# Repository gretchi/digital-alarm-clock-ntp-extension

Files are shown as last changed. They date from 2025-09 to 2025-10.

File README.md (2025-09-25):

# digital-alarm-clock-ntp-extension

## ボタン配置

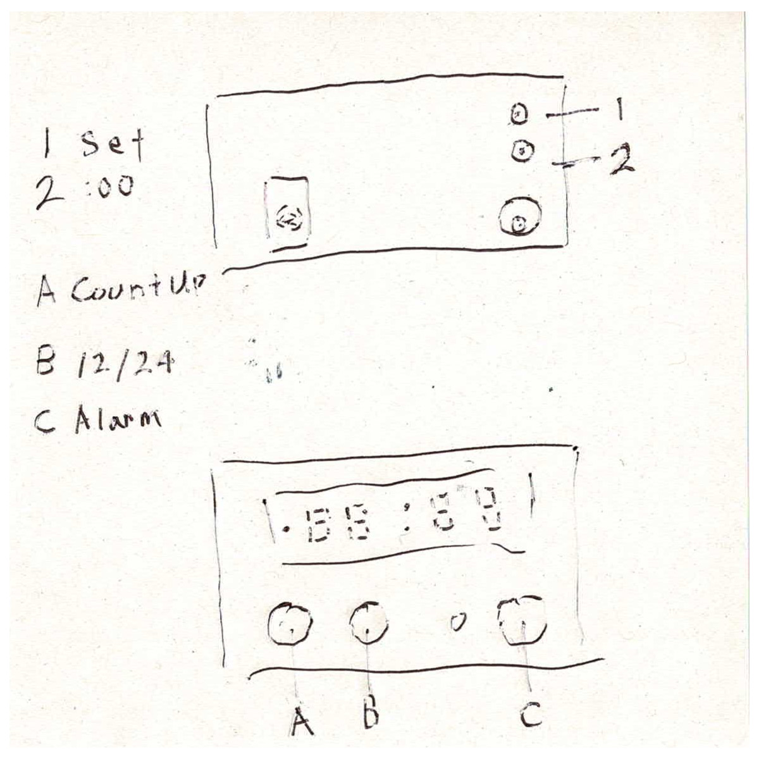
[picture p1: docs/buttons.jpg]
buttons


## フロー

### ブート

1. ネットワーク確立
2. NTP日時取得

### 電源投入直後

1. `Btn_1` High -> Low (時計を開始)

### 日時合わせ

1. ボタン操作回数を計算し、操作開始をスケジュール
    1. ssが正時となるタイミングにmm + 1回目のエミュレートが行われるようエミュレート開始タイミングをスケジュール
2. `Btn_1` High -> Low
3. `Btn_A` hh++
4. `Btn_B` mm++

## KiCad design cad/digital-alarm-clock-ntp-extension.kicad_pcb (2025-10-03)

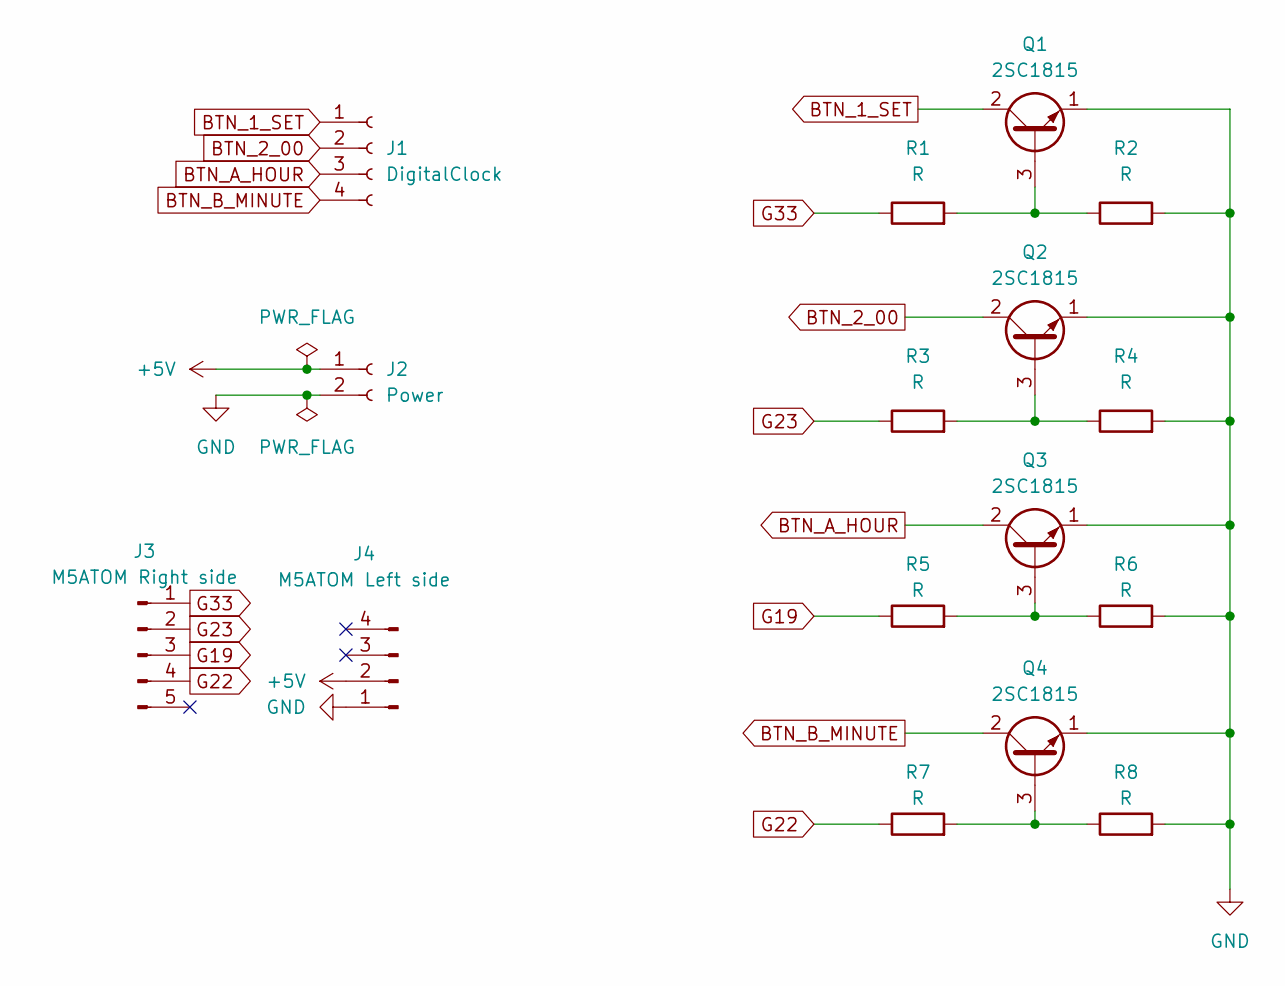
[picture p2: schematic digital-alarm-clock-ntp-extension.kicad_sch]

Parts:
J1: DigitalClock; JST_XH_B4B-XH-A_1x04_P2.50mm_Vertical
J2: Power; JST_XH_B2B-XH-A_1x02_P2.50mm_Vertical
J3: M5ATOM Right side; PinHeader_1x05_P2.54mm_Vertical
J4: M5ATOM Left side; PinHeader_1x04_P2.54mm_Vertical
Q1, Q2, Q3, Q4: 2SC1815; TO-92_Inline_Wide
R1, R3, R5, R7: R; R_Axial_DIN0207_L6.3mm_D2.5mm_P10.16mm_Horizontal
R2, R4, R6, R8: R; R_Axial_DIN0204_L3.6mm_D1.6mm_P5.08mm_Vertical

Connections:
+5V: J2.1, J4.2
BTN_1_SET: J1.1, Q1.2 (C)
BTN_2_00: J1.2, Q2.2 (C)
BTN_A_HOUR: J1.3, Q3.2 (C)
BTN_B_MINUTE: J1.4, Q4.2 (C)
G19: J3.3, R5.1
G22: J3.4, R7.1
G23: J3.2, R3.1
G33: J3.1, R1.1
GND: J2.2, J4.1, Q1.1 (E), Q2.1 (E), Q3.1 (E), Q4.1 (E), R2.2, R4.2, R6.2, R8.2
unnamed: Q1.3 (B), R1.2, R2.1
unnamed: Q2.3 (B), R3.2, R4.1
unnamed: Q3.3 (B), R5.2, R6.1
unnamed: Q4.3 (B), R7.2, R8.1

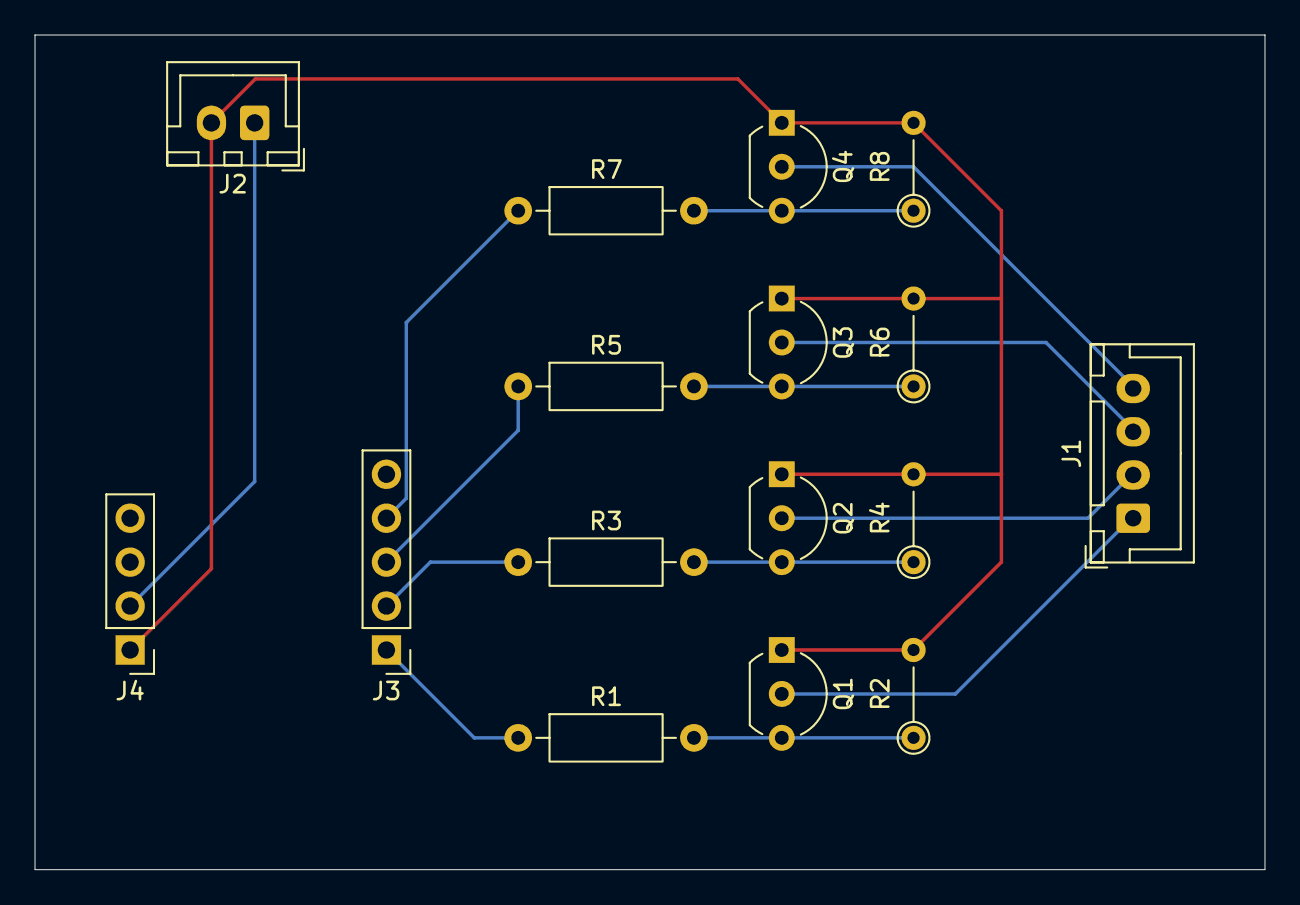
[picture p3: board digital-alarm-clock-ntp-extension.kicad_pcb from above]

Board: 2 copper layers, 71.1 x 48.3 mm, 16 parts (0 on the bottom side), 14 nets.

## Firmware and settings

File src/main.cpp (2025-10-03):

#include <Arduino.h>
#include <M5Atom.h>
#include <WiFiManager.h>
#include <WiFi.h>
#include "app_wifi.h"

const int BTN_1_SET = 33;
const int BTN_2_00 = 23;
const int BTN_A_HOUR = 19;
const int BTN_B_MINUTE = 22;
const int PRESS_MS = 100;

extern WiFiManager wm;
extern String configure_ssid;
extern String configure_password;

void press_ms(int gpio, int ms);

void setup()
{
    M5.begin(true, false, true);
    Serial.begin(115200);
    M5.dis.drawpix(0, 0xFF0000);

    pinMode(BTN_1_SET, INPUT);
    pinMode(BTN_2_00, INPUT);
    pinMode(BTN_A_HOUR, INPUT);
    pinMode(BTN_B_MINUTE, INPUT);

    initAppWiFi();
    Serial.printf("Configure Wi-Fi SSID: %s, Password: %s\n", configure_ssid.c_str(), configure_password.c_str());
    if (WiFiConnect() == 0)
    {
        Serial.println("Wi-Fi not connecting");
    }
    M5.dis.drawpix(0, 0x008000);

    press_ms(BTN_1_SET, PRESS_MS);
    delay(5000);

    press_ms(BTN_1_SET, PRESS_MS);
    for (int i = 0; i < 3; i++)
    {
        press_ms(BTN_A_HOUR, PRESS_MS);
        delay(300);
    }
    for (int i = 0; i < 15; i++)
    {
        press_ms(BTN_B_MINUTE, PRESS_MS);
        delay(300);
    }
}

void press_ms(int gpio, int ms)
{
    pinMode(gpio, OUTPUT);
    M5.dis.drawpix(0, 0x0080FF);
    digitalWrite(gpio, HIGH);
    delay(ms);
    pinMode(gpio, INPUT);
    M5.dis.drawpix(0, 0x008000);
    delay(ms);
}

void loop()
{
    M5.update();
    delay(100);
}

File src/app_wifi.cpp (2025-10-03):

#include "app_wifi.h"

#include <Arduino.h>
#include "M5Atom.h"

WiFiManager wm;
extern bool is_loop;

const String password_spec_chars = "2345679abcdefghjkmnopqrstuvwxyzACDEFGHJKLMNOPQRSTUVWXYZ"; // 55文字

String configure_ssid = "";
String configure_password = "";

void generateConfigureSSID()
{
    String mac_addr = String(WiFi.macAddress());
    mac_addr.replace(":", "");

    configure_ssid = "DigitalClock"
                     "_" +
                     mac_addr;
}

void initAppWiFi()
{
    generateConfigureSSID();
    generateConfigurePassword();
}

void generateConfigurePassword()
{
    String mac_addr = String(WiFi.macAddress());
    mac_addr.replace(":", "");
    char bytes_mac_addr[13] = {};
    mac_addr.toCharArray(bytes_mac_addr, 13);

    uint64_t seed = 0;
    for (int i = 0; i < 8; i++)
    {
        char c = bytes_mac_addr[12 - i];
        seed = seed << 8 | (uint64_t)c & 0xFF;
    }

    seed ^= 0x543D3449AC073FA0LL; // デタラメな数列をXOR

    // 乱数生成器初期化
    randomSeed(seed);

    configure_password = "";

    for (int i = 0; i < 10; i++)
    {
        int s = random(55);
        configure_password = configure_password + password_spec_chars.substring(s, s + 1);
    }
}

void getSSID(char *ssidBuffer, size_t bufferSize)
{
    String ssid = WiFi.SSID();

    strncpy(ssidBuffer, ssid.c_str(), bufferSize - 1);
    ssidBuffer[bufferSize - 1] = '\0';
}

int WiFiConnect()
{
    if (WiFi.isConnected())
    {
        Serial.println("already connected");
        return 0;
    }

    // 設定済みWi-Fiへ接続
    wm.setEnableConfigPortal(false);

    for (int i = 0; i < 3; i++)
    {
        if (wm.autoConnect())
        {
            Serial.println("successful new connection");
            return 0;
        }

        delay(5000);
        Serial.println("retry to connect");
    }

    // 新規接続
    wm.setEnableConfigPortal(true);

    if (wm.autoConnect(configure_ssid.c_str(), configure_password.c_str()))
    {
        if (WiFi.psk().compareTo("") == 0)
        {
            // オープンネットワークへの接続は禁止
            Serial.println("connecting to an open network is prohibited");
            wm.resetSettings();
            ESP.restart();
        }
        Serial.println("successful new connection");
        return 0;
    }

    Serial.println("failed to connect");

    return -1;
}

// void wifi_state()
// {
//     static bool wifi_status_lump_state = 0;

//     if (WiFi.status() == WL_CONNECTED)
//     {
//         // Wi-Fi接続中
//         M5.dis.drawpix(PIX_POS_WIFI_STATE, PIX_COL_WIFI_CONNECTED);
//     }
//     else
//     {
//         // Wi-Fi未接続
//         if (wifi_status_lump_state == 1)
//         {
//             M5.dis.drawpix(PIX_POS_WIFI_STATE, PIX_COL_WIFI_DISCONNECTED);
//         }
//         else
//         {
//             M5.dis.drawpix(PIX_POS_WIFI_STATE, PIX_COL_BLACK);
//         }
//     }

//     if (!is_loop)
//     {
//         // loopが実行されていない場合、Updateを代理
//         M5.update();
//     }

//     wifi_status_lump_state = !wifi_status_lump_state;
// }

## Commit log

2025-09-18 feat(custom):
    platform io プロジェクト作成
2025-09-25 feat(custom):
    動作確認用ソース
2025-09-26 feat(custom):
    cad
    [digital-alarm-clock-ntp-extension.kicad_pcb, digital-alarm-clock-ntp-extension.kicad_sch]
2025-10-03 feat: 回路図、基板のピンアサインの修正
    [digital-alarm-clock-ntp-extension.kicad_pcb, digital-alarm-clock-ntp-extension.kicad_sch]
2025-10-03 add 動作確認用の点滅を追加
2025-10-03 feat(custom):
    wi-fi接続とボタン定義
